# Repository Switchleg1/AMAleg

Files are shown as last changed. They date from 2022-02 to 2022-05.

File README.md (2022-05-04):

# AMAleg
DIY Macchina A0 Clone built from parts attainable from amazon. <br><br>

<p align="center">
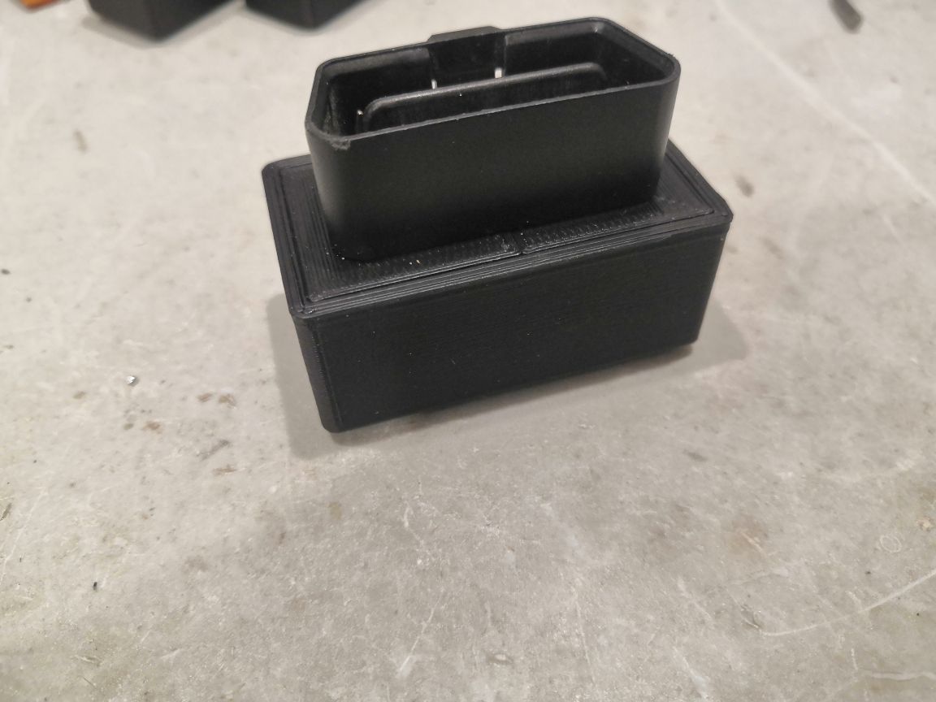
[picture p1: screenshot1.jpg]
  
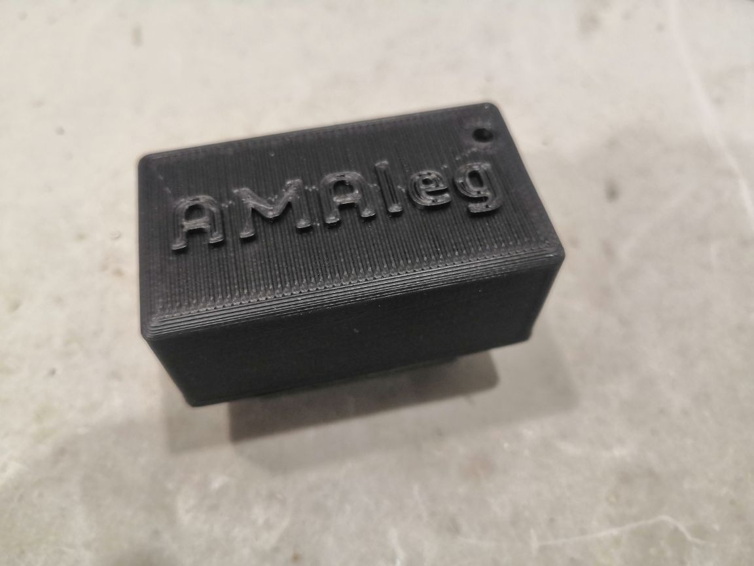
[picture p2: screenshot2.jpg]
  
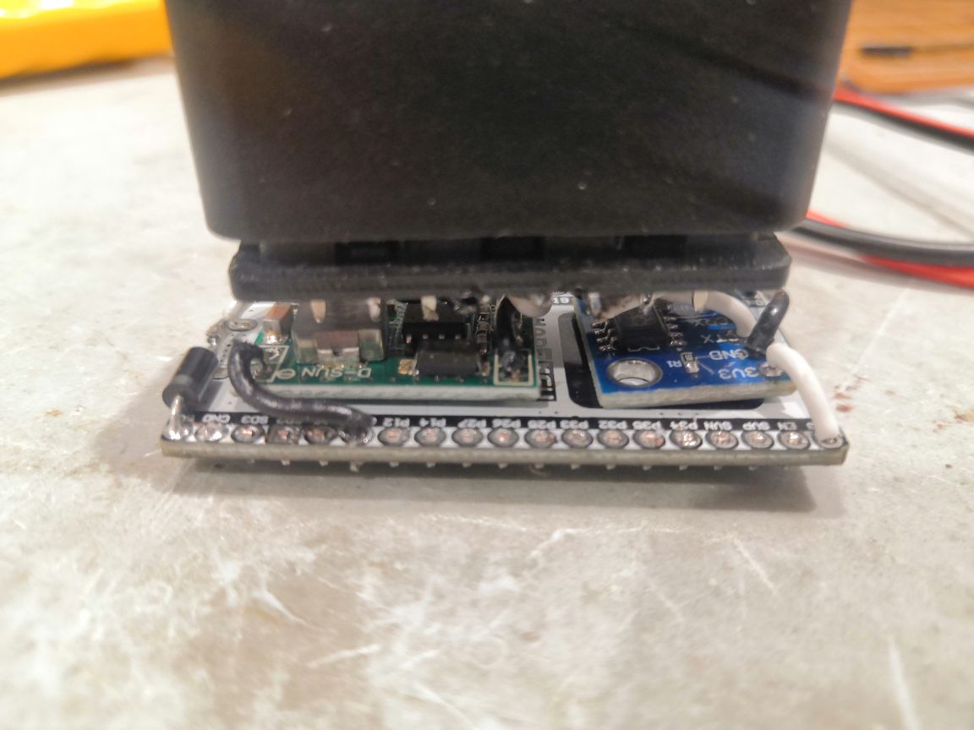
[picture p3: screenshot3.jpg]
  
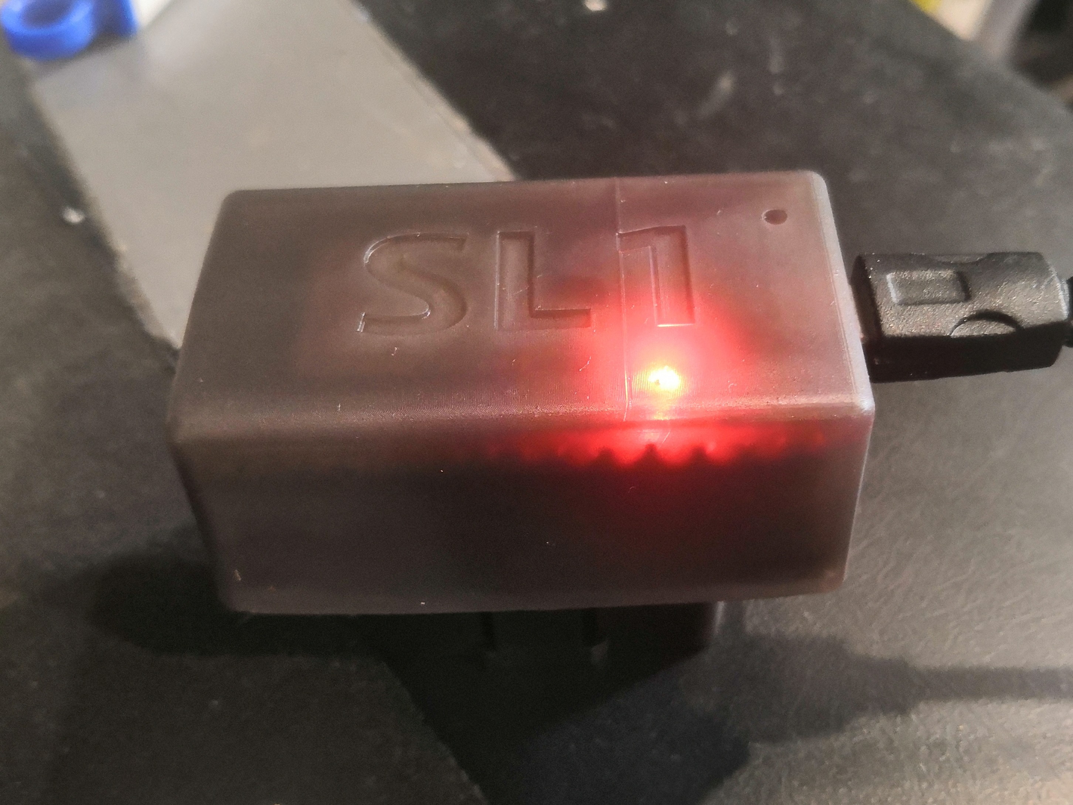
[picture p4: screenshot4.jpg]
  
</p><br>

Case Models: <br>
For OBD connectors with 1.5mm flanges and the smaller KeeYee esp32 boards<br>
Top (you may need to oversize 1% depending on material and printer calibration) <br>
https://github.com/Switchleg1/AMAleg/blob/main/SL1.3.5-top.STL<br>
Bottom (x2) <br>
https://github.com/Switchleg1/AMAleg/blob/main/SL1.3.5-bottom_half.STL<br><br>

For OBD connectors with 1.5mm flanges and the larger esp32 boards with mounting holes<br>
Top (you may need to oversize 1% depending on material and printer calibration) <br>
https://github.com/Switchleg1/AMAleg/blob/main/SL1.5-top.STL<br>
Bottom (x2) <br>
https://github.com/Switchleg1/AMAleg/blob/main/SL1.5-bottom_half.STL<br><br>

For OBD connectors with 2mm flanges (not common)<br>
Top <br>
https://github.com/Switchleg1/AMAleg/blob/main/top.STL<br>
Bottom (x2) <br>
https://github.com/Switchleg1/AMAleg/blob/main/bottom_half.STL<br><br>

Parts list (quantity 1 of each): <br>
Any ESP32 dev board <br>
https://www.amazon.ca/KeeYees-Development-Bluetooth-Microcontroller-ESP-WROOM-32/dp/B07PP1R8YK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 <br><br>
SN65HVD230 breakout board - **Watch out for fakes, take note of how long they have been selling for and if they are less than $3usd each it is probably fake, if the last line of the chip reads 'ctcv04' it is a fake (though there are more fakes these have been tested).<br>
It appears all of the square boards are probably fakes at the moment and the only luck we have seen are with the rectangle board. ** 
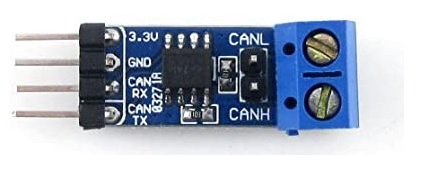
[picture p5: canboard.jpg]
<br>
https://www.amazon.ca/SN65HVD230-CAN-Board-Communication-Development/dp/B00KM6XMXO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 <br><br>
Any MP1584 based buck converter <br>
https://www.amazon.ca/eBoot-MP1584EN-Converter-Adjustable-Module/dp/B01MQGMOKI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 <br><br>
OBD2 connector (can also be taken from an elm adapter) <br>
https://www.sparkfun.com/products/9911 <br><br>
Schottky or fast recovery diode (1Amp 20v) 1N5819, SR100, UF4004, etc <br>
https://www.amazon.ca/1N5819-Schottky-Barrier-Rectifier-DO-204AL/dp/B07RL3SCL4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<br><br>

Wire diagram:<br>
<p align="center">
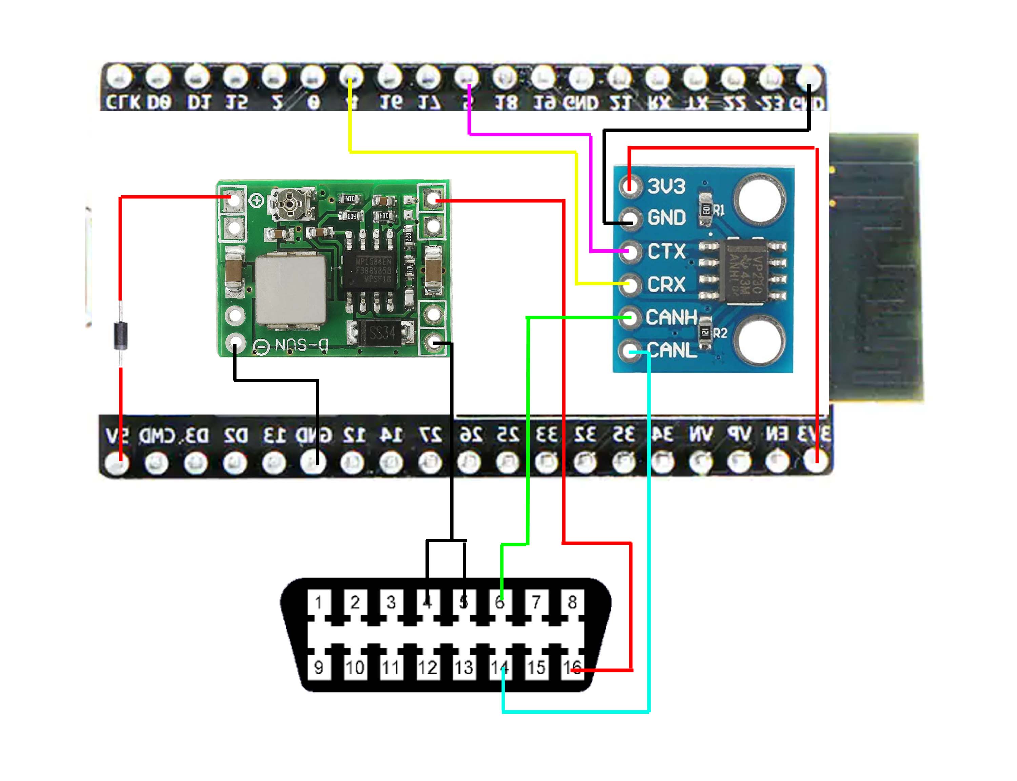
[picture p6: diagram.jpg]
  
</p><br>

After assembling remember to set the voltage regulator anywhere from 5-5.5v (turn knob clockwise by 1/10th of a turn) and flash the latest firmware https://github.com/Switchleg1/esp32-isotp-ble-bridge

Print layout:<br>
Always print with logo facing up with support material.  If printing with ABS i recommend a peelable raft.
<p align="center">
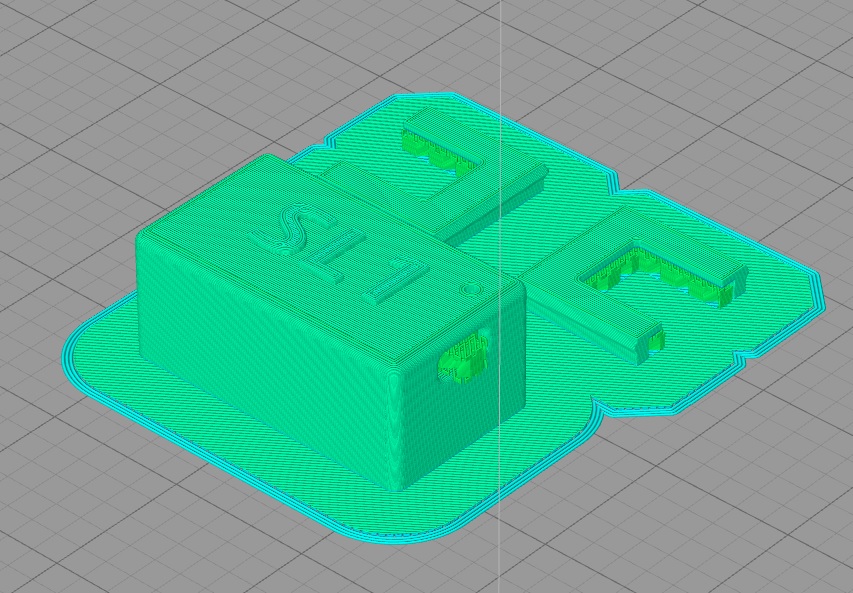
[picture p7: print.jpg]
  
</p><br>

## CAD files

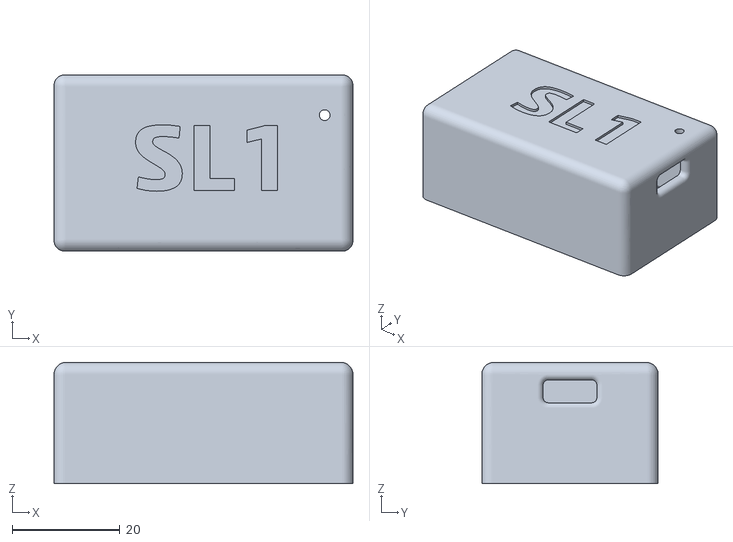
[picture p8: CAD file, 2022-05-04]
SL1.5-top.STL
55.5 x 32.7 x 22.5

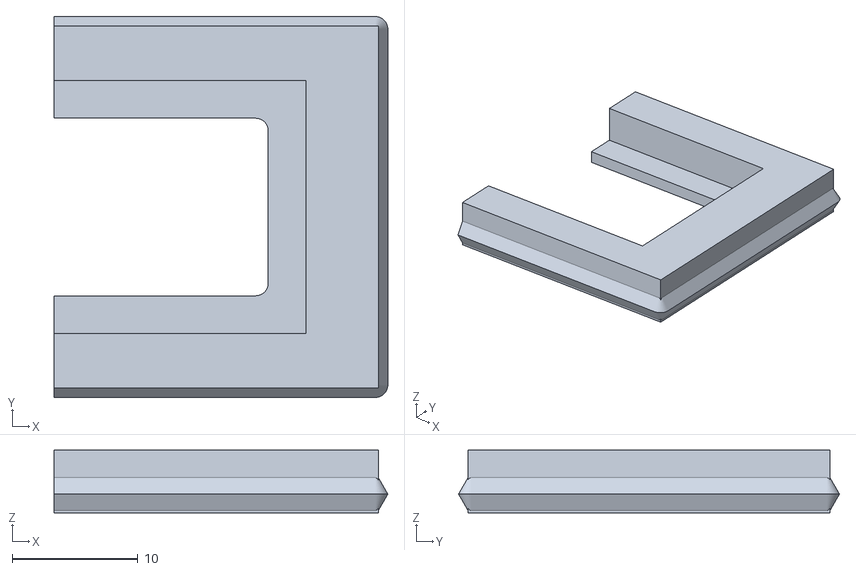
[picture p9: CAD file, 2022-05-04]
SL1.5-bottom_half.STL
26.5 x 30.3 x 5.00

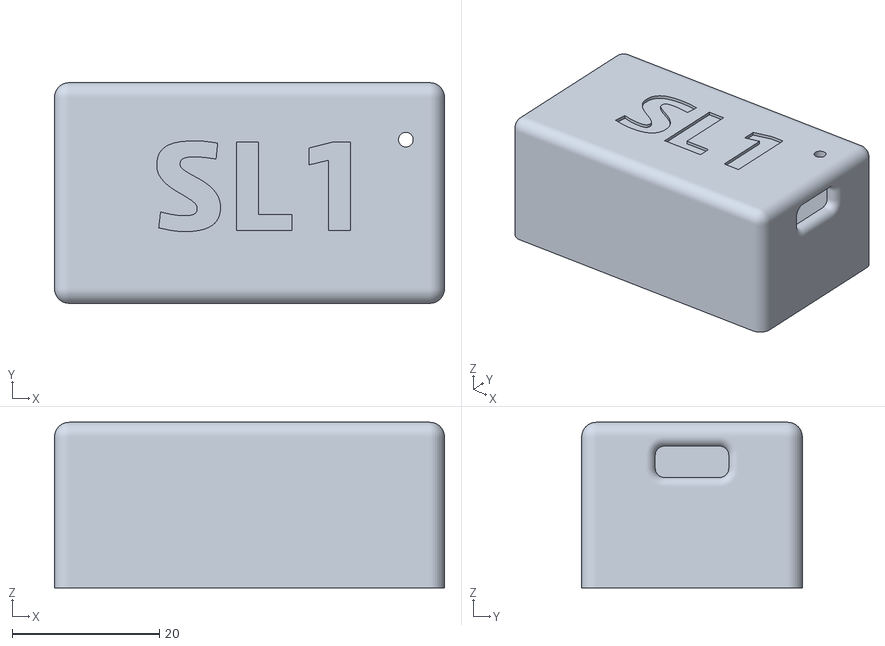
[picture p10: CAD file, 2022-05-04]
SL1.3.5-top.STL
53.0 x 30.0 x 22.5

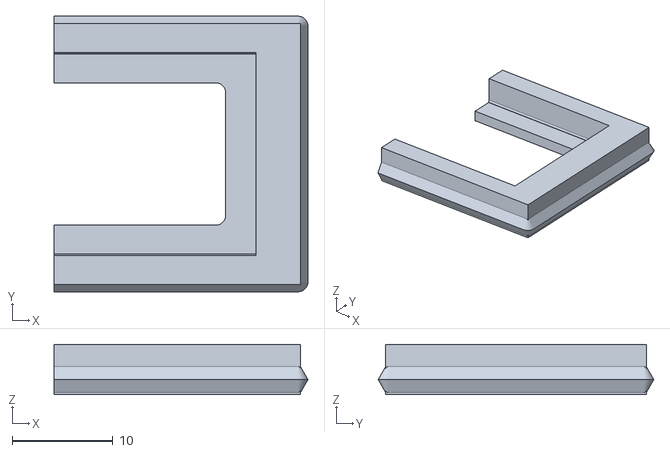
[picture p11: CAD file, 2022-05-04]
SL1.3.5-bottom_half.STL
25.1 x 27.3 x 5.00

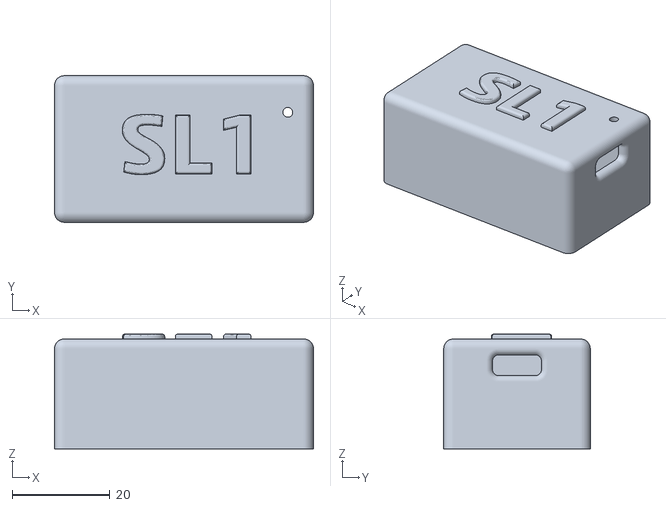
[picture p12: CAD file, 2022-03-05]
SL1.3-top.STL
53.0 x 30.0 x 23.5

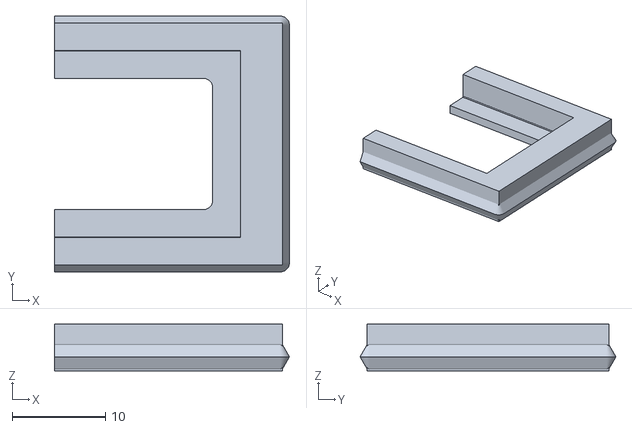
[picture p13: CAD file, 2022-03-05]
SL1.3-bottom_half.STL
25.2 x 27.5 x 5.00

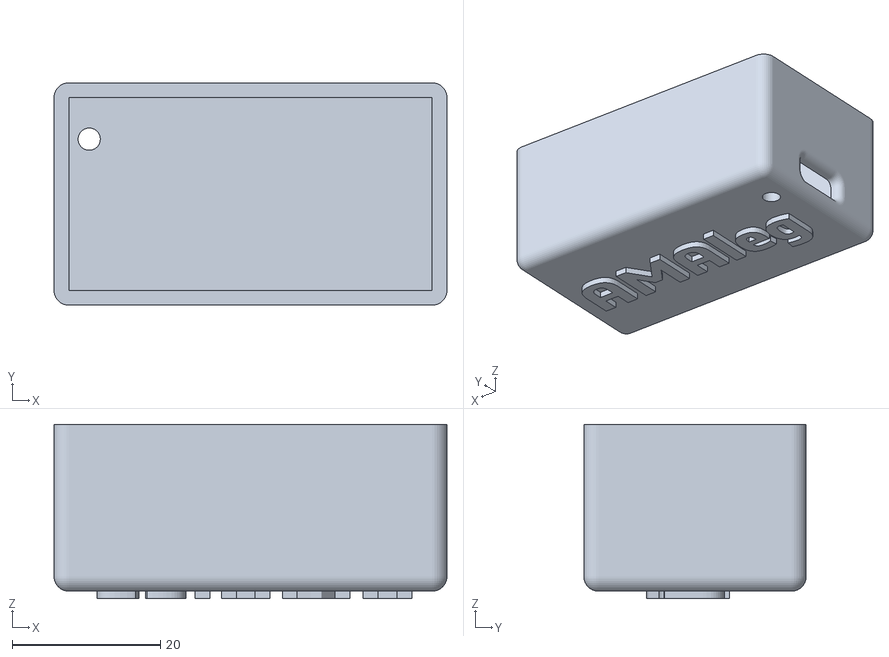
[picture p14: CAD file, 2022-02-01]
top.STL
53.0 x 30.0 x 23.5

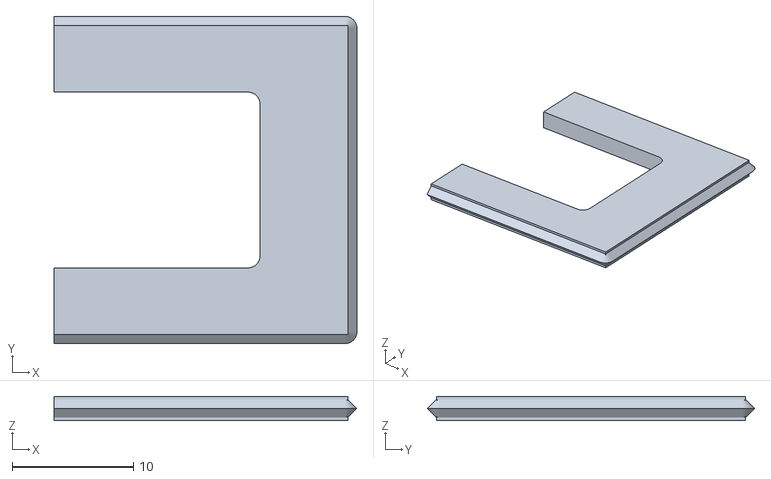
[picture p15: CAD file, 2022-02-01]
bottom_half.STL
25.0 x 27.0 x 2.00

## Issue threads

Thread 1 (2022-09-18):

AMAleg CAN transceiver details

Arpy222, 2022-09-18:
Hi!
Some details are not clear for me related to the CAN transceiver, could you give me some help related to that?

1. Is 120 Ohm termination resistor needed on the CAN bus (so between CANH and CANL)?
2. In which mode do you use the SN65HVD23x chip? In high speed mode, or is it recommended to use slope control? If that is necessary, then what resistor value do you use on the Rs pin?

Thanks for your help!
Regards,
  Arpad

Switchleg1, 2022-09-18:
You plan to build your own can transceiver board?  If so I would suggest
reading the datasheet, termination resistor isn't truly required but its
standard practice and comes included in the dev boards purchased from
amazon.  The dev boards should come with slope control enabled but
unfortunately I don't have any on hand to confirm.

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

Arpy222, 2022-09-28:
Hi!
Sorry for the late reaction, I forgot to write a response. :(
Yes I plan to build it on a prototype board, using an SO8 -> DIP8 converter, using the specific chip type.
On the picture you have uploaded [https://raw.githubusercontent.com/Switchleg1/AMAleg/main/diagram.jpg](LINK)
There are indeed two resistors:
- marked as 121 (120 Ohm, so a CAN bus termination resistor)
- marked as 103 (10 kOhm, probably for the slope control, which means slew rate of ~15 V/μs)
Then I guess you have not modified the board which came from Amazon, rather used it as is.

Thanks for your help!
Regards,
  Arpad

Switchleg1, 2022-09-28:
Correct though I make my own boards now using the mcp2551 as it's more
readily available.

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

Closed 2023-01-19.

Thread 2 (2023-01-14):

1A 20V is 1N5817  you have it listed as the 1N5819 which is the 1A 40V

k0rtalian, 2023-01-14:

Switchleg1, 2023-01-14:
1A 20v is the minimum.  I then list multiple different common diodes of various ratings that will work.  Schottky or any ultrafast diode will work in this scenario.

leahcornelius, 2023-05-09:
Why does it need to be a Schottky exactly? Is it not just there to prevent the ESP leaking current into (trying to power) the buck converter when it is connected to USB but not a car? They have a smaller voltage drop sure but that doesn't really matter when you are feeding into the Vin pin. the LDOs on the esps operate quite happily between 4->7v so if a silicone diode's voltage drop was too large you could just adjust the buck converter's output to compensate, no?
